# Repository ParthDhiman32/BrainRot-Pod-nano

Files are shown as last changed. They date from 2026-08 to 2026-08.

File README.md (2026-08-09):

# BrainRot-Pod-nano
BrainRot Pod Nano is an overengineered Embedded system project wth complex PCB and beautiful CAD enclosure mainly made for playing meme sounds and also can work as a mini music player   

# Motivation to create this and Outline of features
okay so this sounds like a really dumb project but the thing is this is a really good project infact this project will help me sharpen my PCB and CAD skills to a even newer level Because i will try my best to Make this project as polished as possible like i want to make this project as perfect as it could be 
I wanted to make a project to see what level are my skills are at.

My goals for this project are to mainly have a Beauitiful! PCB which is really pleasing to an engineers eyes and to also design an enclosure which encapsulates the beauty of the PCB while itself mantaining a really Smooth Sleek and Matte design 

This project will have a shitload of features ranging from a rotatory encoder to adjust the volume to a SD card module to load your songs to and even a AUX Jack because..WHY NOT!!! 

I want to mantain a sleek design like how apple iPODs used to be like and also make my own UI and UX for this project and Many tactile buttons for feedback maybe i'll even add a vibrating motor for haptic feedback

# Main Components Used:
1.  ESP32-S3-WROOM-1 Module 
2.  PCM5102A - Audio DAC
3.  MAX98357A - Audio Amplifer 
4.  TP4056 - Li-Po charger IC 
5.  DW01A - Battery Protection IC 
6.  FS83205A - Power Mosfet 
7.  ME6211 - LDO Regulator 
8.  AO3400 - BacLight Switch for TFT 
9.  1.54" SPI TFT display
10. Li-Po battery - 1100mAh 3.7V
11. Speaker - 3W 4Ω dynamic speaker
12. Rotary Encoder SMD
13. Tactile Buttons SMD 
14. USB C connector - 16 pin tactile receptacle 
15. Audio Jack - PJ-320A 3.5mm Stereo Audio Jack
16. SD Card slot - Push Pull SD card slot 
17. Battry connector - JST battery connector 
18. A lot of passive resistors 
19. A lot of passive capacitors 
20. M2 screws 

## Reason for selection of each part 
 1. ESP32-S3-WROOM-1 Module - this specific module was selected because it has 8MB of PSRAM which acts as the DMA audio buffer also because it has more than enough processing power and as it also has wifi and bluetooth i can add these features later to my project 

 2. PCM5102A - Normally audio DACs require bulky DC blocking Capacitors but as this IC has a negative voltage rail which produces ground centered Audio this eliminates the need of those bulky DC Blosking capacitors 

 3. MAX93857A - this is an Mono Class-D audio amplifer IC (amp for short) and it shares the common I2C bus as the DAC and also it will shut off automatically when the Audio jack / AUX will be connected 

 4. TP4056 - This is a very common Typical Li-Po battery chargin IC no need for more explanation

 5. DW01A - This is a battery protection IC which is paired with TP4056 which provides Short Circuit and overload protection to the battery 

 6. AP2112K-3.3 - This is a ultra low dropout power regulator meaning it will extract maximum voltage from the Lipo battery before it drops out it drops out around 3.55V unlike older inefficient AMS117 which dropout at around 4.3V

 7. ME6211 - efficiently converts the 5V from the power system to 3V3 volts the entire circuitry works on

 8. AO3400 - This is a simple PWM switch which will be used to control the intensity of Backlight of the 2.8" TFT Display 

 9.  1.54" SPI TFT display - Very high quality display with vivid range of colours and no grainy text 

 10. 1100mAh Li-Po battery provied long enough battery life that if optmized could give all day long runtime 
 
 11. 3W 4Ω dynamic speaker - Loud enough speaker and also can be driven Efficiently by our Audio amplifier circuitry 

 12. Rotary Encoder - To simply control the Volume 

 13. Tactile Buttons - Buttons with 5-20N of actuation force so that it gives a premium click! feel 

 14. USB C connector - for charging the battery and flashing / Updating the firmware 

 15. Audio Jack - Only to connect external wired earphones

 16. SD Card slot - Ti store Songs / MEME sounds 

 17. Battery Connector - A JST batter connector to prevent accidental rever polatiy connections 

 18. 19.  resistors and capacitors - Do i even need to explain why this is needed 

 20. M2 screws are small enough to be screwed and not be noticed easily

# PCB Schematics

## Complete Schematic

<p align="center">
  Complete Schematic
</p>

---

## Complete PCB

### Op-Amps & Audio Circuit

<p align="center">
  Audio Amplifier
</p>

<p align="center">
  Audio System Schematic
</p>

---

## Power System

<p align="center">
  Power System
</p>

---

## ESP32 & Peripheral Connections

<p align="center">
  ESP32 and Peripheral Connections
</p>

# CAD DESIGN 
BrainRot_Pod_Nano_PCB_assembly v11

BrainRot_Pod_Nano_PCB_assembly v11 V2

BrainRot_Pod_Nano_PCB_assembly v11 V3

# BOM

| # | Component | Qty | Estimated Unit Cost | Estimated Total |
|---|---|---:|---:|---:|
| 1 | ESP32-S3-WROOM-1, 8MB PSRAM | 1 | $3.70 | $3.70 |
| 2 | PCM5102A Audio DAC | 1 | $1.25 | $1.25 |
| 3 | MAX98357A Class-D Audio Amplifier | 1 | $1.05 | $1.05 |
| 4 | TP4056 Li-Po Charger IC | 1 | $0.16 | $0.16 |
| 5 | DW01A Battery Protection IC | 1 | $0.11 | $0.11 |
| 6 | FS8205A / FS83205A Battery Protection MOSFET | 1 | $0.11 | $0.11 |
| 7 | ME6211 / AP2112K 3.3V LDO | 1 | $0.16 | $0.16 |
| 8 | AO3400 Backlight MOSFET | 1 | $0.08 | $0.08 |
| 9 | 1.54" SPI TFT Display | 1 | $2.63 | $2.63 |
| 10 | 3.7V 1100mAh Li-Po Battery | 1 | $3.15 | $3.15 |
| 11 | 3W 4Ω Dynamic Speaker | 1 | $1.05 | $1.05 |
| 12 | SMD Rotary Encoder | 1 | $0.42 | $0.42 |
| 13 | SMD Tactile Buttons | ~6 | $0.05 | $0.32 |
| 14 | USB-C 16-Pin Receptacle | 1 | $0.21 | $0.21 |
| 15 | PJ-320A 3.5mm Stereo Audio Jack | 1 | $0.21 | $0.21 |
| 16 | Push-Pull SD Card Socket | 1 | $0.42 | $0.42 |
| 17 | JST Battery Connector | 1 | $0.16 | $0.16 |
| 18 | Resistors | ~20–30 | — | $0.32 |
| 19 | Capacitors | ~20–30 | — | $0.63 |
| 20 | Misc. Diodes / LEDs / Small Components | — | — | $0.32 |
| 21 | M2 Screws + Mechanical Hardware | — | — | $0.53 |
| | **TOTAL ROUGH BOM ESTIMATE** | | | **≈ $17.01** |
| | **Recommended Budget Range** | | | **$17–$20** |

> **Note:** This is a rough prototype estimate. Actual prices may vary depending on the supplier, exact MPNs, quantity, shipping, and taxes. PCB manufacturing, assembly, and 3D-printing costs are **not included**.

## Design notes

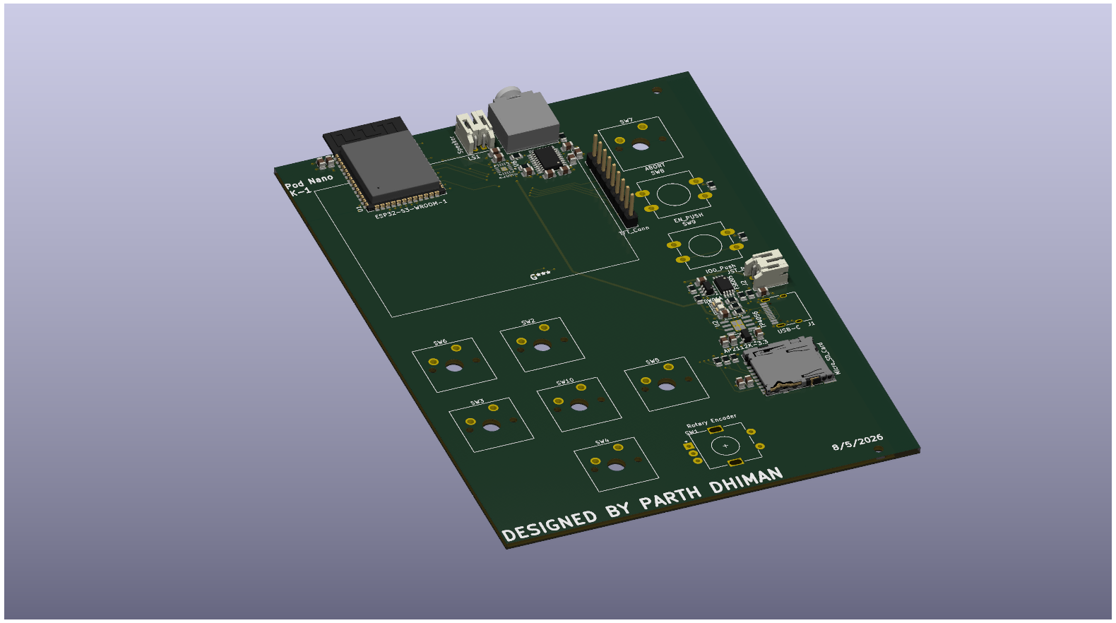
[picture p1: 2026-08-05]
PCB/PCB-Renders/Brain_Rot_Pod_Nano_PCB_v1.png

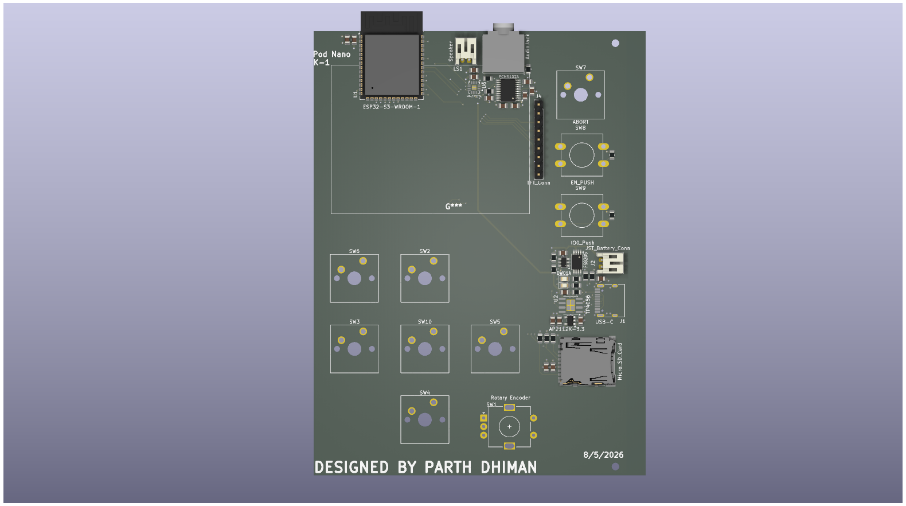
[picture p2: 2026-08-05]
PCB/PCB-Renders/Brain_Rot_Pod_Nano_PCB.png

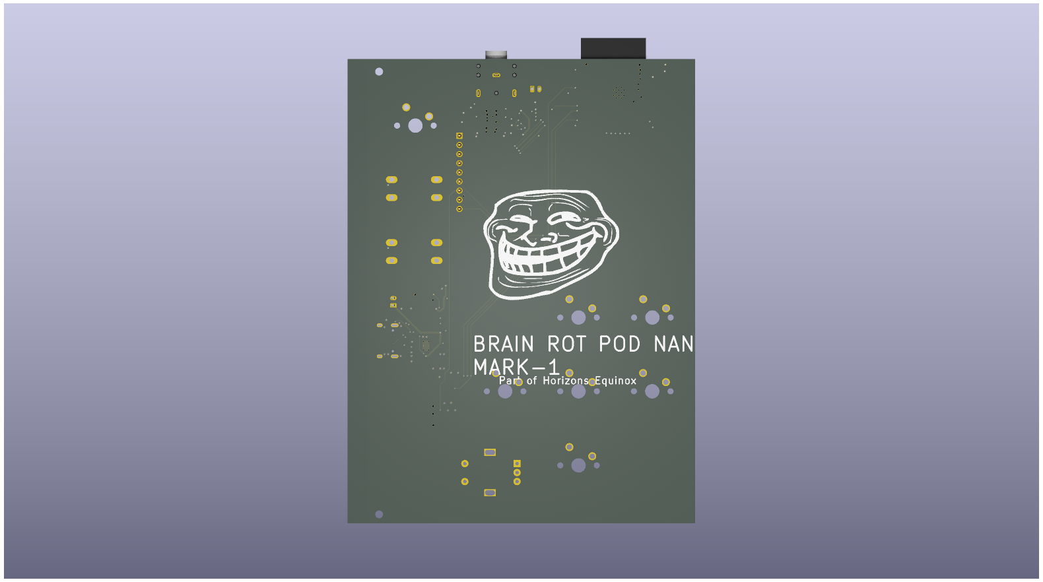
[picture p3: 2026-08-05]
PCB/PCB-Renders/Brain_Rot_Pod_Nano_PCB_v2.png

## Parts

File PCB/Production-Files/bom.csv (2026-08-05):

Designator | Footprint | Quantity | Value | LCSC Part #
C1, C15, C18, C2, C4, C5, C8 | 0805 | 7 | 10uF
C10, C11, C14, C16, C17, C3, C6, C7, C9 | 0805 | 9 | 0.1uF
C12, C13 | 0805 | 2 | 2.2uF
D1 | 0805 | 1 | RLED
D2 | 0805 | 1 | GLED
J1 | USB_C_Receptacle_HRO_TYPE-C-31-M-12 | 1 | USB-C
J2 | JST_PH_S2B-PH-K_1x02_P2.00mm_Horizontal | 1 | JST_Battery_Conn
J3 | Jack_3.5mm_CUI_SJ1-3523N_Horizontal | 1 | AudioJack
J4 | PinHeader_1x09_P2.54mm_Vertical | 1 | TFT_Conn
J5 | microSD_HC_Hirose_DM3AT-SF-PEJM5 | 1 | Micro_SD_Card
LS1 | JST_PH_S2B-PH-K_1x02_P2.00mm_Horizontal | 1 | Speaker
Q1 | TSSOP-8_4.4x3mm_P0.65mm | 1 | FS8205
R1, R2 | 0805 | 2 | 5.1kR
R10, R6, R9 | 0805 | 3 | 100R
R11, R12, R13, R3 | 0805 | 4 | 4.7kR
R16, R17, R8 | 0805 | 3 | 10kR
R4, R5, R7 | 0805 | 3 | 1kR
SW1 | RotaryEncoder_Alps_EC11E-Switch_Vertical_H20mm | 1 | Rotary Encoder
SW10, SW5 | SW_Cherry_MX_1.00u_PCB | 2 | UI4
SW2 | SW_Cherry_MX_1.00u_PCB | 1 | UI1
SW3 | SW_Cherry_MX_1.00u_PCB | 1 | UI2
SW4 | SW_Cherry_MX_1.00u_PCB | 1 | UI3
SW6 | SW_Cherry_MX_1.00u_PCB | 1 | BOOT
SW7 | SW_Cherry_MX_1.00u_PCB | 1 | ABORT
SW8 | SW_PUSH-12mm | 1 | EN_PUSH
SW9 | SW_PUSH-12mm | 1 | IO0_Push
U1 | ESP32-S3-WROOM-1 | 1 | ESP32-S3-WROOM-1
U2 | SOIC-8-1EP_3.9x4.9mm_P1.27mm_EP2.41x3.3mm_ThermalVias | 1 | TP4056
U3 | SOT-23-6 | 1 | DW01A
U4 | SOT-23-5 | 1 | AP2112K-3.3
U5 | TSSOP-20_4.4x6.5mm_P0.65mm | 1 | PCM5102A
U6 | TQFN-16-1EP_3x3mm_P0.5mm_EP1.23x1.23mm | 1 | MAX98357A

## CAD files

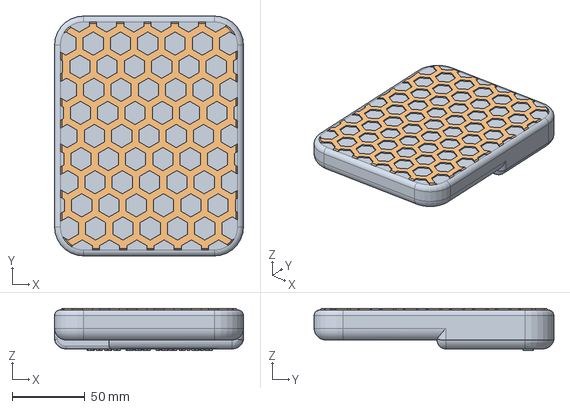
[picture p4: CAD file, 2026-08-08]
CAD/Enlcosure/BrainRot_Pod_Nano_Enclosure Part-1 v46.step
129.9 x 164.8 x 29.0 mm

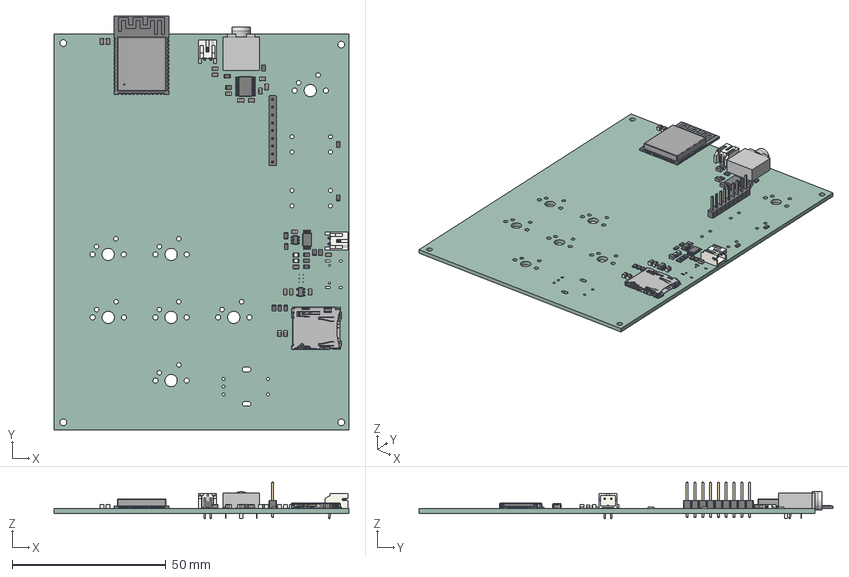
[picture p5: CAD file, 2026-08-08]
PCB/PCB_STEP_File/Brain_Rot_Pod_Nano_PCB.step
96.0 x 134.8 x 11.9 mm
R_0805_2012Metric x 15
C_0805_2012Metric x 18
PinHeader_1x09_P2.54mm_Vertical
microSD_HC_Hirose_DM3AT-SF-PEJM5
SOT-23-6
SOT-23-5
LED_0805_2012Metric x 2
TSSOP-20_4.4x6.5mm_P0.65mm
Jack_3.5mm_CUI_SJ1-3523N_Horizontal
JST_PH_S2B-PH-K_1x02_P2.00mm_Horizontal x 2
TSSOP-8_4.4x3mm_P0.65mm
ESP32-S3-WROOM-1
Brain_Rot_Pod_Nano_PCB_PCB

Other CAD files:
CAD/Enlcosure/BrainRot_Pod_Nano_Enclosure Part-1 v46.f3d

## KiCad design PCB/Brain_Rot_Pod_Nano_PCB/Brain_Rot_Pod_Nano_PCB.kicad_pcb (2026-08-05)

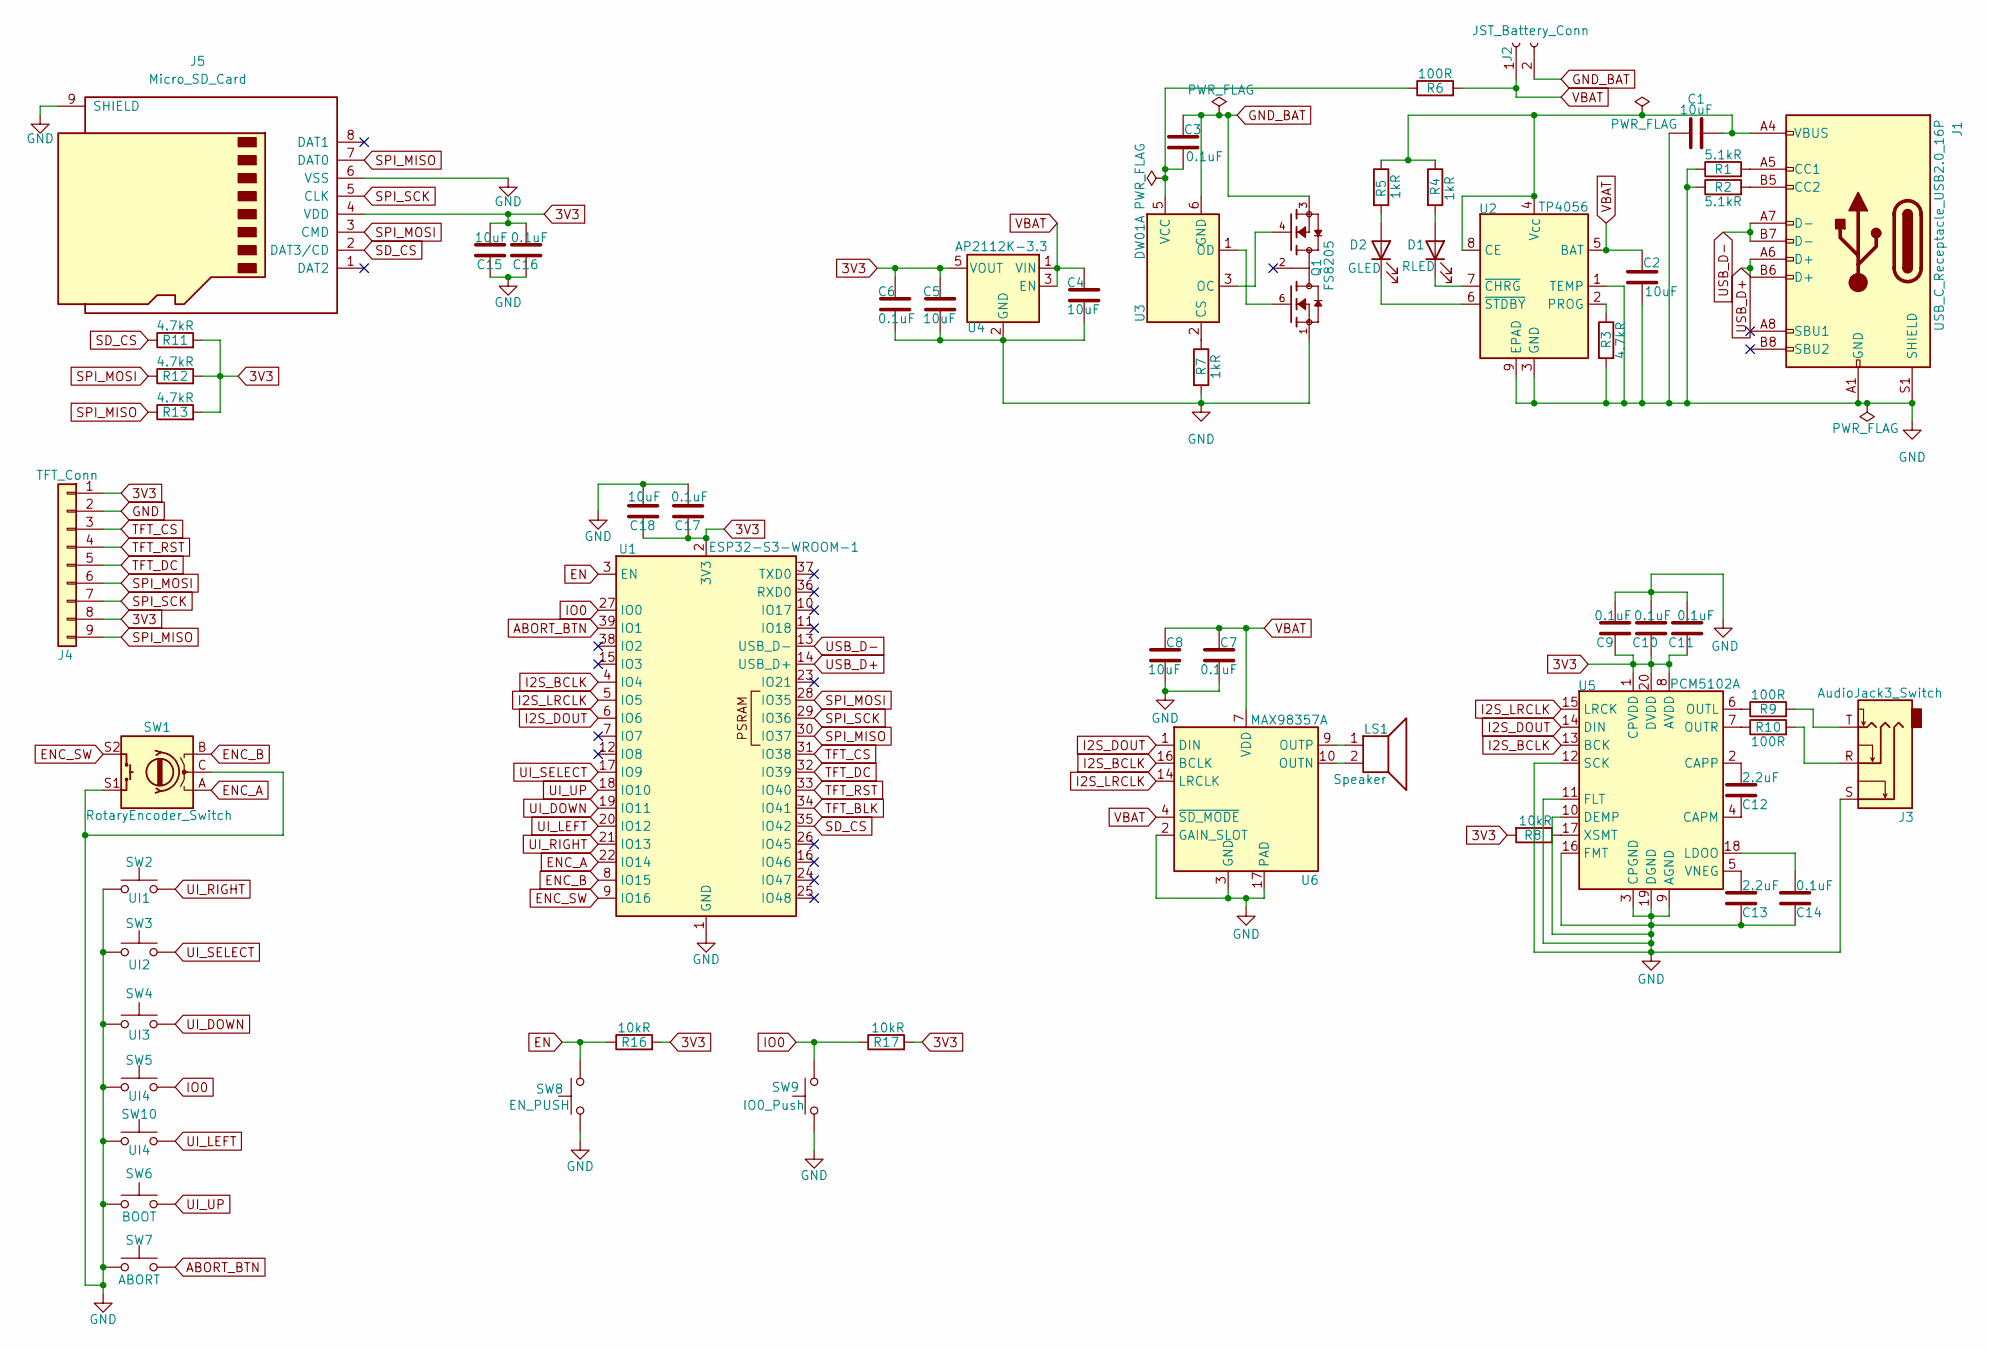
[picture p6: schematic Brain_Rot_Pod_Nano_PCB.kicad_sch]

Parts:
C1, C2, C4, C5, C8, C15, C18: 10uF; C_0805_2012Metric
C3, C6, C7, C9, C10, C11, C14, C16, C17: 0.1uF; C_0805_2012Metric
C12, C13: 2.2uF; C_0805_2012Metric
D1: RLED; LED_0805_2012Metric
D2: GLED; LED_0805_2012Metric
J1: USB_C_Receptacle_USB2.0_16P; USB_C_Receptacle_HRO_TYPE-C-31-M-12
J2: JST_Battery_Conn; JST_PH_S2B-PH-K_1x02_P2.00mm_Horizontal
J3: AudioJack3_Switch; Jack_3.5mm_CUI_SJ1-3523N_Horizontal
J4: TFT_Conn; PinHeader_1x09_P2.54mm_Vertical
J5: Micro_SD_Card; microSD_HC_Hirose_DM3AT-SF-PEJM5
LS1: Speaker; JST_PH_S2B-PH-K_1x02_P2.00mm_Horizontal
Q1: FS8205; TSSOP-8_4.4x3mm_P0.65mm; PARTREV 1.9
R1, R2: 5.1kR; R_0805_2012Metric
R3, R11, R12, R13: 4.7kR; R_0805_2012Metric
R4, R5, R7: 1kR; R_0805_2012Metric
R6, R9, R10: 100R; R_0805_2012Metric
R8, R16, R17: 10kR; R_0805_2012Metric
SW1: RotaryEncoder_Switch; RotaryEncoder_Alps_EC11E-Switch_Vertical_H20mm
SW2: UI1; SW_Cherry_MX_1.00u_PCB
SW3: UI2; SW_Cherry_MX_1.00u_PCB
SW4: UI3; SW_Cherry_MX_1.00u_PCB
SW5, SW10: UI4; SW_Cherry_MX_1.00u_PCB
SW6: BOOT; SW_Cherry_MX_1.00u_PCB
SW7: ABORT; SW_Cherry_MX_1.00u_PCB
SW8: EN_PUSH; SW_PUSH-12mm
SW9: IO0_Push; SW_PUSH-12mm
U1: ESP32-S3-WROOM-1
U2: TP4056; SOIC-8-1EP_3.9x4.9mm_P1.27mm_EP2.41x3.3mm_ThermalVias
U3: DW01A; SOT-23-6
U4: AP2112K-3.3; SOT-23-5
U5: PCM5102A; TSSOP-20_4.4x6.5mm_P0.65mm
U6: MAX98357A; TQFN-16-1EP_3x3mm_P0.5mm_EP1.23x1.23mm

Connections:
3V3: C5.1, C6.1, C9.2, C10.2, C11.2, C15.1, C16.1, C17.2, C18.2, J4.1, J4.8, J5.4 (VDD), R8.2, R11.2, R12.2, R13.2, R16.2, R17.2, U1.2 (3V3), U4.5 (VOUT), U5.1 (CPVDD), U5.8 (AVDD), U5.20 (DVDD)
ABORT_BTN: SW7.2, U1.39 (IO1)
EN: R16.1, SW8.2, U1.3 (EN)
ENC_A: SW1.A, U1.22 (IO14)
ENC_B: SW1.B, U1.8 (IO15)
ENC_SW: SW1.S2, U1.9 (IO16)
GND: C1.1, C2.1, C4.2, C5.2, C6.2, C7.2, C8.2, C9.1, C10.1, C11.1, C13.2, C14.2, C15.2, C16.2, C17.1, C18.1, J1.A1 (GND), J1.A12 (GND), J1.B1 (GND), J1.B12 (GND), J1.S1 (SHIELD), J3.S, J4.2, J5.6 (VSS), J5.9 (SHIELD), Q1.1, R1.1, R2.1, R3.2, R7.2, SW1.C, SW1.S1, SW2.1, SW3.1, SW4.1, SW5.1, SW6.1, SW7.1, SW8.1, SW9.1, SW10.1, U1.1 (GND), U1.40 (GND), U1.41 (GND), U2.1 (TEMP), U2.3 (GND), U2.9 (EPAD), U4.2 (GND), U5.3 (CPGND), U5.9 (AGND), U5.10 (DEMP), U5.11 (FLT), U5.12 (SCK), U5.16 (FMT), U5.19 (DGND), U6.2 (GAIN_SLOT), U6.3 (GND), U6.11 (GND), U6.15 (GND), U6.17 (PAD)
GND_BAT: C3.1, J2.2, Q1.3, U3.6 (GND)
I2S_BCLK: U1.4 (IO4), U5.13 (BCK), U6.16 (BCLK)
I2S_DOUT: U1.6 (IO6), U5.14 (DIN), U6.1 (DIN)
I2S_LRCLK: U1.5 (IO5), U5.15 (LRCK), U6.14 (LRCLK)
IO0: R17.1, SW5.2, SW9.2, U1.27 (IO0)
unnamed: D1.2 (A), R4.2
unnamed: D1.1 (K), U2.7 (~CHRG)
unnamed: D2.2 (A), R5.2
unnamed: D2.1 (K), U2.6 (~STDBY)
unnamed: J1.A5 (CC1), R1.2
unnamed: J1.B5 (CC2), R2.2
unnamed: J3.R, R10.2
unnamed: J3.T, R9.2
unnamed: C1.2, J1.A4 (VBUS), J1.A9 (VBUS), J1.B4 (VBUS), J1.B9 (VBUS), R4.1, R5.1, U2.4 (V_{CC}), U2.8 (CE)
unnamed: R3.1, U2.2 (PROG)
unnamed: R7.1, U3.2 (CS)
unnamed: Q1.4, U3.3 (OC)
unnamed: Q1.6, U3.1 (OD)
unnamed: C3.2, R6.1, U3.5 (VCC)
unnamed: C12.2, U5.4 (CAPM)
unnamed: C12.1, U5.2 (CAPP)
unnamed: C14.1, U5.18 (LDOO)
unnamed: R9.1, U5.6 (OUTL)
unnamed: R10.1, U5.7 (OUTR)
unnamed: C13.1, U5.5 (VNEG)
unnamed: R8.1, U5.17 (XSMT)
unnamed: LS1.2, U6.10 (OUTN)
unnamed: LS1.1, U6.9 (OUTP)
SD_CS: J5.2 (DAT3/CD), R11.1, U1.35 (IO42)
SPI_MISO: J4.9, J5.7 (DAT0), R13.1, U1.30 (IO37)
SPI_MOSI: J4.6, J5.3 (CMD), R12.1, U1.28 (IO35)
SPI_SCK: J4.7, J5.5 (CLK), U1.29 (IO36)
TFT_BLK: U1.34 (IO41)
TFT_CS: J4.3, U1.31 (IO38)
TFT_DC: J4.5, U1.32 (IO39)
TFT_RST: J4.4, U1.33 (IO40)
UI_DOWN: SW4.2, U1.19 (IO11)
UI_LEFT: SW10.2, U1.20 (IO12)
UI_RIGHT: SW2.2, U1.21 (IO13)
UI_SELECT: SW3.2, U1.17 (IO9)
UI_UP: SW6.2, U1.18 (IO10)
USB_D+: J1.A6 (D+), J1.B6 (D+), U1.14 (USB_D+)
USB_D-: J1.A7 (D-), J1.B7 (D-), U1.13 (USB_D-)
VBAT: C2.2, C4.1, C7.1, C8.1, J2.1, R6.2, U2.5 (BAT), U4.1 (VIN), U4.3 (EN), U6.4 (~SD_MODE), U6.7 (VDD), U6.8 (VDD)

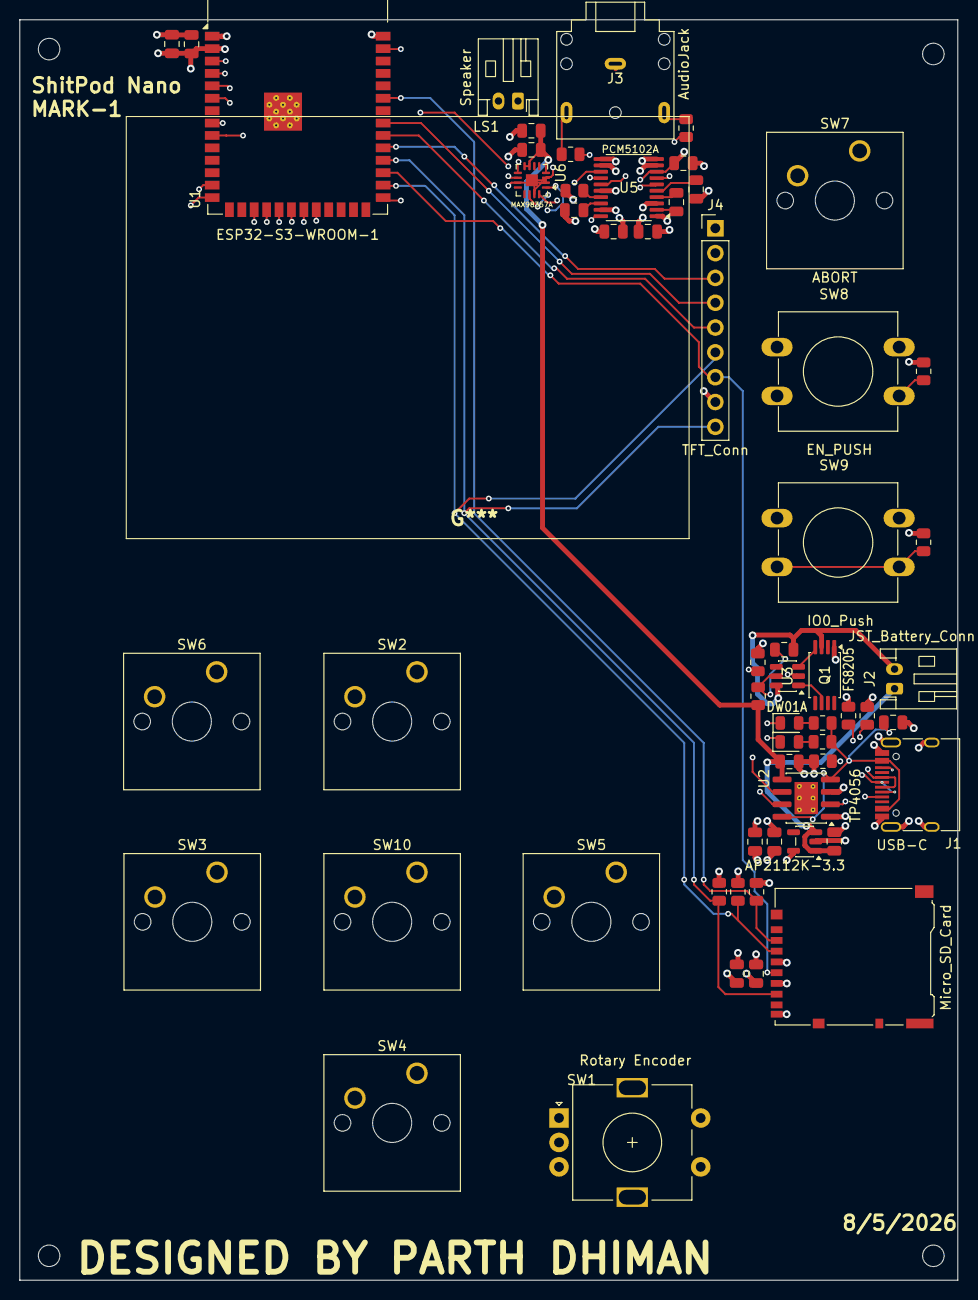
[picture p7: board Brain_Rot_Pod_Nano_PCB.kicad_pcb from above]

Board: 6 copper layers, 96.0 x 129.0 mm, 58 parts (0 on the bottom side), 50 nets.

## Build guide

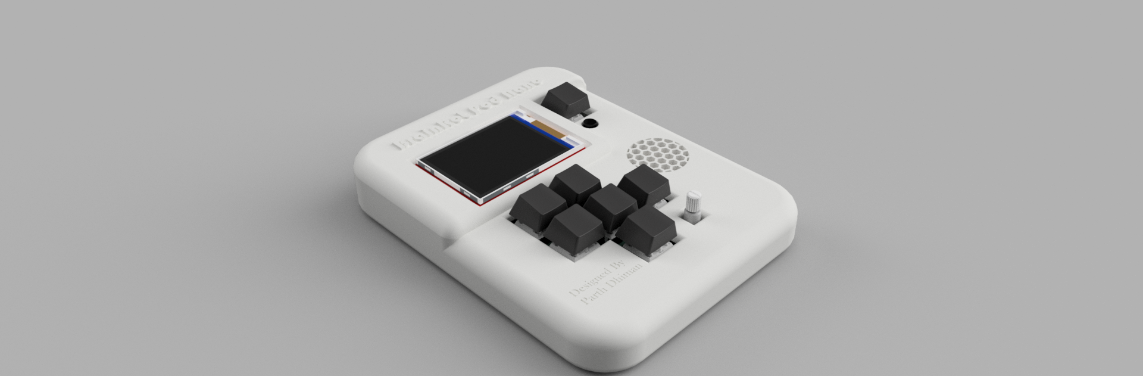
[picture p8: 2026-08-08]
CAD/Renders/BrainRot_Pod_Nano_PCB_assembly v11 V2.png

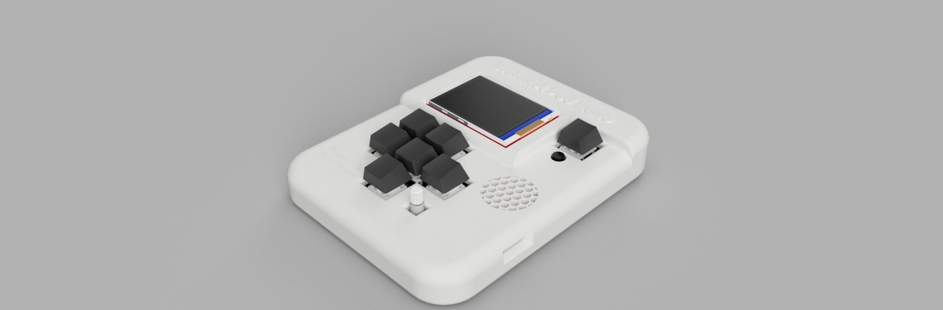
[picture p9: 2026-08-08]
CAD/Renders/BrainRot_Pod_Nano_PCB_assembly v11.png

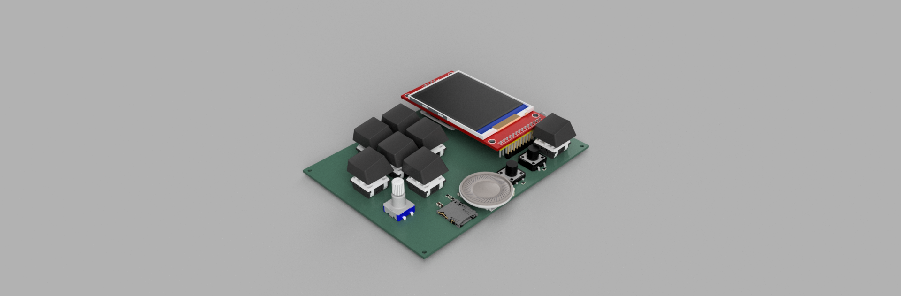
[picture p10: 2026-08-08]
CAD/Renders/BrainRot_Pod_Nano_PCB_assembly v11 V3.png

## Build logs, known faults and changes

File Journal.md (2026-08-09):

---
Title: "BrainRot_Pod_Nano"
Author: "Parth Dhiman"
Description: "BrainRot_Pod_Nano is a overengineered Music player / Meme sound player"
Created_at: "2026-8-3"
---

# 3rd August: Setting up Brain_Rot_Pod_Nano!
SO GUYZ this is my very first journal entry for BrainRot_Pod_Nano and i am really excited to work on this project also i might someplaces accidentally refer to BrainRot_Pod_Nano as ShitPod_Nano both mean the same thing so yeah don't get confused 

Anyways so first of all today i created a github repository for BrainRot_Pod_Nano and then i added a very brief description to it 

then i went on to connect this project with Hackatime to tract the coding time and the time spent on journals and Readme more importantly i synced my hackatime and lapse so that my total wok is properly synced 

Then i listed all the Main components i will need for making this project in the readme one thing i would like to clearly state that i use gemini for helping me on this project in what way? let me explain it researches the best parts and suggests me the best ones then i go ahead to research on that specific recommended part making my own decision if i shall use this one or any different part i read the datasheet and see the Typical application circuit to judge for the part selection 

then i also stated why did i use that specific part in the readme 

after writing all the readme stuff i started to place all the components on the schematic sheet i placed the power system first then the audio system and then MCU in the center of the sheet and then i added the storage and display part on the top left of the sheet and then lastly i added all the switches where they were needed to be placed and then i took gemini's ADVICE on where to keep the components and then how to add them so that it causes the lest problem in tomorrow's schematic and also as we are overengineering this we are trying to perfect every single aspect of this Schematic 

Here is today's work 



**Total time spent ~2.5 hours (including lapse and journal)**

# 4th August: Started and finished PCB Schematics! 

SSOOOO guysss today i started the pcb schematics for BrainRot Pod Nano and i am really excited to overenginner every part 
so first of all i started by wiring up the Power Subsystem and adding passive SMD components required fot it 
then i started to wire the subsystem and wired and organized everything as cleanely as i possibly could 
so first of all we started by connection the 5.1kR resistors on the CC1 and CC2 of the USB-c connector....by doing this it tells the Charger to provide 5V to the USB port

then i went over and added decoupling capacitors at the input and output of every IC to stablize power then i added a 4.7kR pull down resistor to the PROG pin of the TP4056 to set the charging current to 250mAh 
and finally added LEDs and also wired up the short circuit protection circuit  

overall i expect the power system to wqork flawlessly because i also rechecked every connection using gemini and it also seems to call the system perfect and it should work even with voltage fluctuations and noise 


Next up i will move on to the audio DAC and amplification circuitry for the speaker connection and the AUX port connections 


okay so this is the schematics of the speaker subsystem 


The audio is handeled by the PCM5102A low ground centered DAC it recieves the digital audio streams from esp32 s3 via the I2S bus the chip had an internal negative charge pump which eliminates the need for the Bulky high power DC blocking capacitors it can automatically switch between speaker mode and AUX audio jack mode 

These are the IU buttons 


one sleek rotatory encoder and 4 switched for navigation and one for booting up and one for aborting and sudden switch off 

This is the entire finished schematic and today's work is said to be complete now 


**Total time spent ~2.5 hours (including lapse and journal)**

# 5th August: Footprint assignment and PCB routing!

SSOOOO GUYYSStoday i skipped school so that i could finish off my PCB today 
So first of all what i did was assign footprints to each and every component from resistors to the auido jack
i had a bit of problem with asigning footprints for the AudioJack because The standard Kicad AudioJack has different pin assignments than the one i was going to be using in real life for this project so i had to modify the pins for the Audio Jack in the schematics for it to properly be connected in the actual PCB 

here is how the PCb looks like for now 
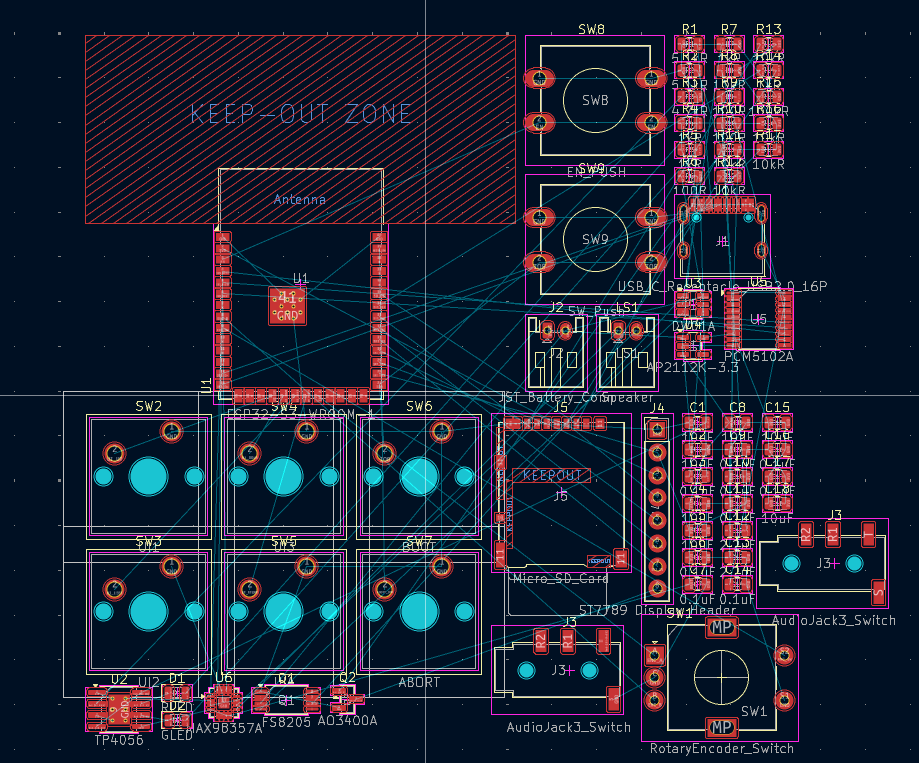
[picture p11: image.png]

and ngl this looks scary complx and it is gonna definitely take a lot of my time but i will patiently deal with this pcb and perfect it cause i am overengineering this project 

Okay so shit it is 1 am of 6th august i worked like the entire day and made huge HUGE HUGE progress so i can only give a brief now so first of all i seperated all the subsystems and then perfected passibe component placement for that subsystem and after that i drew out a 110*80mm edge.cuts layer 

AND THEN I MADE A DECISION First i though i will be making a 2 or 4 layer pcb BUT NO i ended up designing a 6 LAYER PCB!!!! 
AND IT WAS NOT EASY DEFINITELY NOT EASY so after each subsystem's compoinent placement was perfected i went on to arrangeall the buttons in the POD and asked gpt for a reference ideal image and i got an image and basically there will be a cluster of bussons in the below center and a vertical 3 button array on the far right side of the POD and then i started the routing so basically i firstly added GND and 3V3 vias and then started to power first the Power Subsystem and then the Audio subsystem and then then SD card and TFT and then the ESP32 and finally the Buttons and i made Good use of All 6 layers to my advantage and the entire final schematic looks like this  well i also added my name and date of design and ofc it's name "ShitPod_Nano / BrainRot_Nano" and finally also addeda trollface to the back and here is the final thing 


**Total time spent ~6.1 hours (including lapse and journal)**

# 6TH, 7TH, 8TH th August: CAD Design started and fininshed !
Alright guys so these 3 days i woked purely on the CAD of my project and didn't journal because i was so engrossed in CAD design 

so let me give a brief so what i did was first i exported the STEP file of the PCB and then created a plane ontu which i measured the dimensions of my PCB and then i made the walls of the enclosure around it and then i used different tools to measue specific heights mainly the inspect tool but osmehtimes i als had to make a offset sketch and then mesure the specifics on it

after that i added all the switched and then buttons the 2.4" TFT dispplay and finally the speaker also ihad to downgrade from a 2.8" display to a 2.4" display because it was not fitting in the actual design but no worries the pin assignments are exactly thee same 

moving on main things that i did were to measure accuractely to make the designa and then i added precise cutouts for the cherry MX switched anmd the rotary encoder and then i added a hexagonal cutout for the speaker and a cutout for the audio jack and then one for the SD card and then finally i added beutiful fillets and chamers to the design and then i added tis name "Shit Pod nano" anmd then i also added my name and finally i rendered the deisgn in FUIONSFUSION 360 and then wrapped up the entire thing and also i made the display elevated because of it's pins and yeah below is the entire cad deisgn 

BrainRot_Pod_Nano_PCB_assembly v11

BrainRot_Pod_Nano_PCB_assembly v11 V2

BrainRot_Pod_Nano_PCB_assembly v11 V3

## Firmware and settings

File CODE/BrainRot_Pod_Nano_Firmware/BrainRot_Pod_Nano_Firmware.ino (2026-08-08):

// Sample firmware for Brain_Rot_Pod_Nano
// Overengineered Firmware for Overengineered project

#include <SPI.h>
#include <SD.h>
#include <TFT_eSPI.h>
#include "AudioFileSourceSD.h"
#include "AudioGeneratorWAV.h"
#include "AudioOutputI2S.h"

#define I2S_BCLK       4
#define I2S_LRC        5
#define I2S_DOUT       6

#define SD_CS          42
#define SD_MOSI        35
#define SD_MISO        37
#define SD_CLK         36

#define ENC_A          14
#define ENC_B          15
#define ENC_SW         16

#define BTN_ABORT      1

enum SystemState {
  STATE_MENU,
  STATE_MUSIC_PLAYING,
  STATE_MEME_SETUP,
  STATE_MEME_ARMED,
  STATE_MEME_PLAYING
};

SystemState currentState = STATE_MENU;

AudioGeneratorWAV *wav;
AudioFileSourceSD *file;
AudioOutputI2S *out;

float currentVolume = 0.6;

uint32_t memeStartTime = 0;
uint32_t memeDelayMs = 60000;
bool memeArmed = false;

uint32_t lastButtonPress = 0;
int lastEncoderState = HIGH;

uint32_t lastUIUpdate = 0;
bool uiNeedsUpdate = true;

TFT_eSPI tft = TFT_eSPI();

void setup() {

  Serial.begin(115200);

  pinMode(ENC_A, INPUT_PULLUP);
  pinMode(ENC_B, INPUT_PULLUP);
  pinMode(ENC_SW, INPUT_PULLUP);

  pinMode(BTN_ABORT, INPUT_PULLUP);

  // Initialize TFT
  tft.init();
  tft.setRotation(1);
  tft.fillScreen(TFT_BLACK);
  tft.setTextColor(TFT_WHITE, TFT_BLACK);

  // Initialize SPI
  SPI.begin(SD_CLK, SD_MISO, SD_MOSI, SD_CS);

  // Initialize SD card
  if (!SD.begin(SD_CS, SPI, 40000000)) {

    tft.drawString("SD CARD FAILED", 10, 10, 2);

    while (1) {
      delay(100);
    }
  }

  // Initialize audio system
  audioLogger = &Serial;

  file = new AudioFileSourceSD();
  out = new AudioOutputI2S();
  wav = new AudioGeneratorWAV();

  // Configure I2S
  out->SetPinout(I2S_BCLK, I2S_LRC, I2S_DOUT);

  // Set initial volume
  out->SetGain(currentVolume);

  uiNeedsUpdate = true;
}


void loop() {

  handleInputs();
  handleAudio();
  handleMemeTimer();
  updateUI();

}


void handleAudio() {

  if (wav && wav->isRunning()) {

    if (!wav->loop()) {

      wav->stop();

      file->close();

      if (currentState == STATE_MEME_PLAYING) {

        currentState = STATE_MENU;
        uiNeedsUpdate = true;

      }
    }
  }
}


void playFile(const char *filename) {

  if (wav->isRunning()) {

    wav->stop();
    file->close();

  }

  if (!file->open(filename)) {

    Serial.print("Failed to open: ");
    Serial.println(filename);

    currentState = STATE_MENU;
    uiNeedsUpdate = true;

    return;
  }

  if (!wav->begin(file, out)) {

    Serial.println("Failed to start WAV playback");

    file->close();

    currentState = STATE_MENU;
    uiNeedsUpdate = true;

    return;
  }
}


void handleInputs() {

  uint32_t now = millis();

  // Button handling
  if (now - lastButtonPress > 50) {

    // Encoder push button
    if (digitalRead(ENC_SW) == LOW) {

      if (currentState == STATE_MUSIC_PLAYING) {

        // Mute / unmute audio
        if (wav->isRunning()) {

          if (currentVolume > 0.0) {
            out->SetGain(0.0);
          }
          else {
            out->SetGain(0.6);
          }

        }

      }

      else if (currentState == STATE_MEME_SETUP) {

        memeArmed = true;
        memeStartTime = now;

        currentState = STATE_MEME_ARMED;

        uiNeedsUpdate = true;

      }

      else if (currentState == STATE_MENU) {

        playFile("/music/song.wav");

        currentState = STATE_MUSIC_PLAYING;

        uiNeedsUpdate = true;

      }

      lastButtonPress = now;
    }


    // Abort button
    if (digitalRead(BTN_ABORT) == LOW) {

      if (wav->isRunning()) {
        wav->stop();
      }

      if (file) {
        file->close();
      }

      memeArmed = false;

      currentState = STATE_MENU;

      uiNeedsUpdate = true;

      lastButtonPress = now;
    }
  }


  // Rotary encoder
  int currentEncoderState = digitalRead(ENC_A);

  if (currentEncoderState != lastEncoderState &&
      currentEncoderState == LOW) {

    if (digitalRead(ENC_B) != currentEncoderState) {

      currentVolume += 0.05;

      if (currentVolume > 1.0) {
        currentVolume = 1.0;
      }

    }
    else {

      currentVolume -= 0.05;

      if (currentVolume < 0.0) {
        currentVolume = 0.0;
      }
    }

    out->SetGain(currentVolume);

    uiNeedsUpdate = true;
  }

  lastEncoderState = currentEncoderState;
}


void handleMemeTimer() {

  if (currentState == STATE_MEME_ARMED && memeArmed) {

    uint32_t now = millis();

    uint32_t elapsed = now - memeStartTime;


    // Update countdown once per second
    if (now - lastUIUpdate >= 1000) {

      uiNeedsUpdate = true;
      lastUIUpdate = now;

    }


    // Timer expired
    if (elapsed >= memeDelayMs) {

      memeArmed = false;

      currentState = STATE_MEME_PLAYING;

      uiNeedsUpdate = true;

      playFile("/memes/faaaah.wav");
    }
  }
}


void updateUI() {

  if (!uiNeedsUpdate) {
    return;
  }

  uiNeedsUpdate = false;

  tft.fillScreen(TFT_BLACK);


  switch (currentState) {

    case STATE_MENU:

      tft.drawString("BRAINROT POD NANO", 10, 10, 4);

      tft.drawString("> MUSIC", 10, 50, 2);

      tft.drawString("  MEME SETUP", 10, 70, 2);

      break;


    case STATE_MUSIC_PLAYING:

      tft.drawString("MUSIC PLAYING", 10, 10, 4);

      tft.drawString("> song.wav", 10, 50, 2);

      tft.drawString("Volume:", 10, 90, 2);

      tft.drawNumber(
        (int)(currentVolume * 100),
        80,
        90,
        2
      );

      break;


    case STATE_MEME_SETUP:

      tft.drawString("MEME SETUP", 10, 10, 4);

      tft.drawString("FAAAAAH.wav", 10, 50, 2);

      tft.drawString("Delay:", 10, 80, 2);

      tft.drawNumber(
        memeDelayMs / 1000,
        80,
        80,
        2
      );

      tft.drawString("SECONDS", 120, 80, 2);

      break;


    case STATE_MEME_ARMED: {

      tft.drawString("MEME TIMER", 10, 10, 4);

      tft.drawString("FAAAAAH.wav", 10, 40, 2);

      uint32_t elapsed = millis() - memeStartTime;

      uint32_t remainingMs = 0;

      if (elapsed < memeDelayMs) {
        remainingMs = memeDelayMs - elapsed;
      }

      uint32_t remaining = remainingMs / 1000;

      tft.drawString("T-MINUS:", 10, 80, 4);

      tft.drawNumber(
        remaining,
        120,
        80,
        4
      );

      break;
    }


    case STATE_MEME_PLAYING:

      tft.fillScreen(TFT_RED);

      tft.setTextColor(TFT_WHITE, TFT_RED);

      tft.drawString("💀", 40, 50, 4);
      tft.drawString("FAAAAAAH", 40, 100, 4);

      tft.setTextColor(TFT_WHITE, TFT_BLACK);

      break;
  }
}

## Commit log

2026-08-03 completed pcb schematic component placement
    [Brain_Rot_Pod_Nano_PCB.kicad_pcb, Brain_Rot_Pod_Nano_PCB.kicad_sch]
2026-08-03 file update push
    [Brain_Rot_Pod_Nano_PCB.kicad_sch]
2026-08-04 updated journal and other files
    [Brain_Rot_Pod_Nano_PCB.kicad_sch]
2026-08-04 saved PCB files
2026-08-05 finished PCB
    [Brain_Rot_Pod_Nano_PCB.kicad_pcb, Brain_Rot_Pod_Nano_PCB.kicad_sch, bom.csv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]
2026-08-05 Finalized PCB design and journalled for today
    [bom.csv, designators.csv, positions.csv]
2026-08-05 updated pcb
    [Brain_Rot_Pod_Nano_PCB.kicad_pcb]
